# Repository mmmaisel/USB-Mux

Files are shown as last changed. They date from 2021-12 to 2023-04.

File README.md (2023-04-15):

# USB-Mux

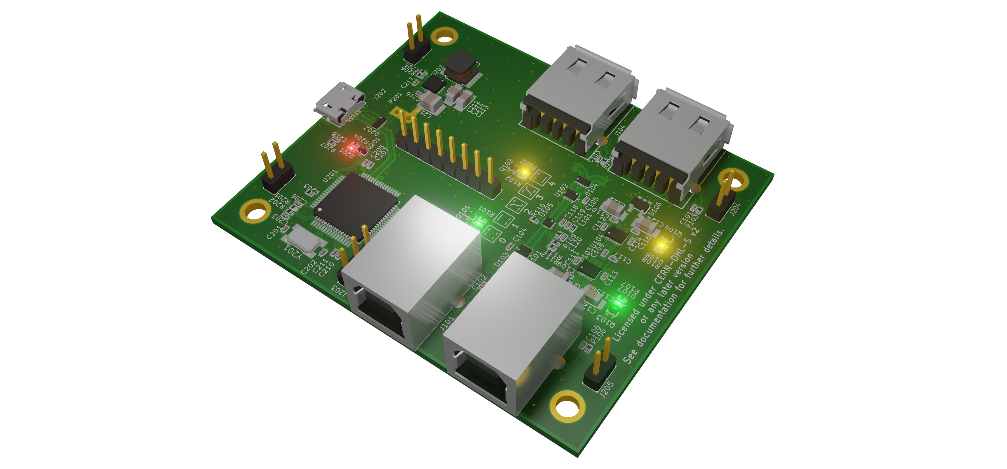
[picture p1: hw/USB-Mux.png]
USB-Mux Rendering


USB-Mux is an Open-Source and Open-Hardware 2x2 USB 2.0 multiplexer.

It supports a single connection between one of the inputs to one of the outputs.
Additionally, it can disconnect the outputs completely. Power flows from the
selected input to the selected output. Inactive output ports are powerless.

Possible applications are switching USB connections in automated tests
or power-cycle a hanging USB device via software.

Binary production files can be downloaded from the
[Releases](https://github.com/mmmaisel/USB-Mux/releases) page.

## Usage

The multiplexer is controlled over USB via a virtual terminal. The virtual
terminal will prompt "Mux:" and accepts a single number between 0 and 4 followed
by a newline to select the multiplexer position.
The meaning of the different numbers is printed on the PCB.

To connect to the virtual terminal on Linux you can use the following command:
`picocom /dev/ttyACM0`

## Programming

Configure the firmware build environment in the 'src' directory with meson
and the supplied cross compiler file.
`meson . build --cross-file cross.build`
Then go into the 'build' directory and build it with `ninja`.

Now, you can program the CPU on the USB-Mux PCB with OpenOCD and an ST-Nucleo
board as programmer with `ninja flash`.

## License

USB-Mux KiCAD hardware design files in the "hw" directory are licenses under the
CERN-OHL-S v2, or (at your option) any later version.

The USB-Mux firmware in the "src" directory is licensed under the
GNU GPLv3, or (at your option) any later version.

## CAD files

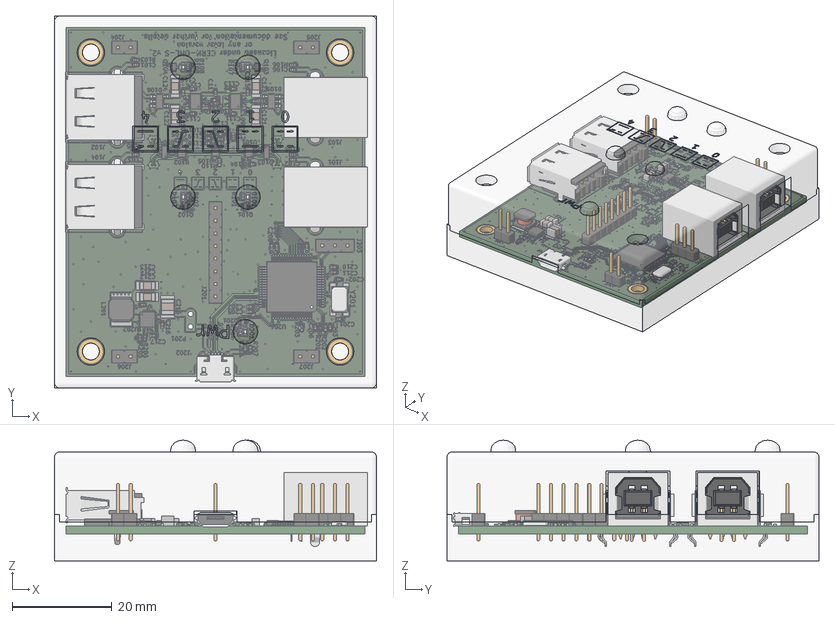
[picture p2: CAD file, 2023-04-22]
hw/USB-Mux-Case.FCStd
64.6 x 74.6 x 24.2 mm
Case-Bot
Case-Top

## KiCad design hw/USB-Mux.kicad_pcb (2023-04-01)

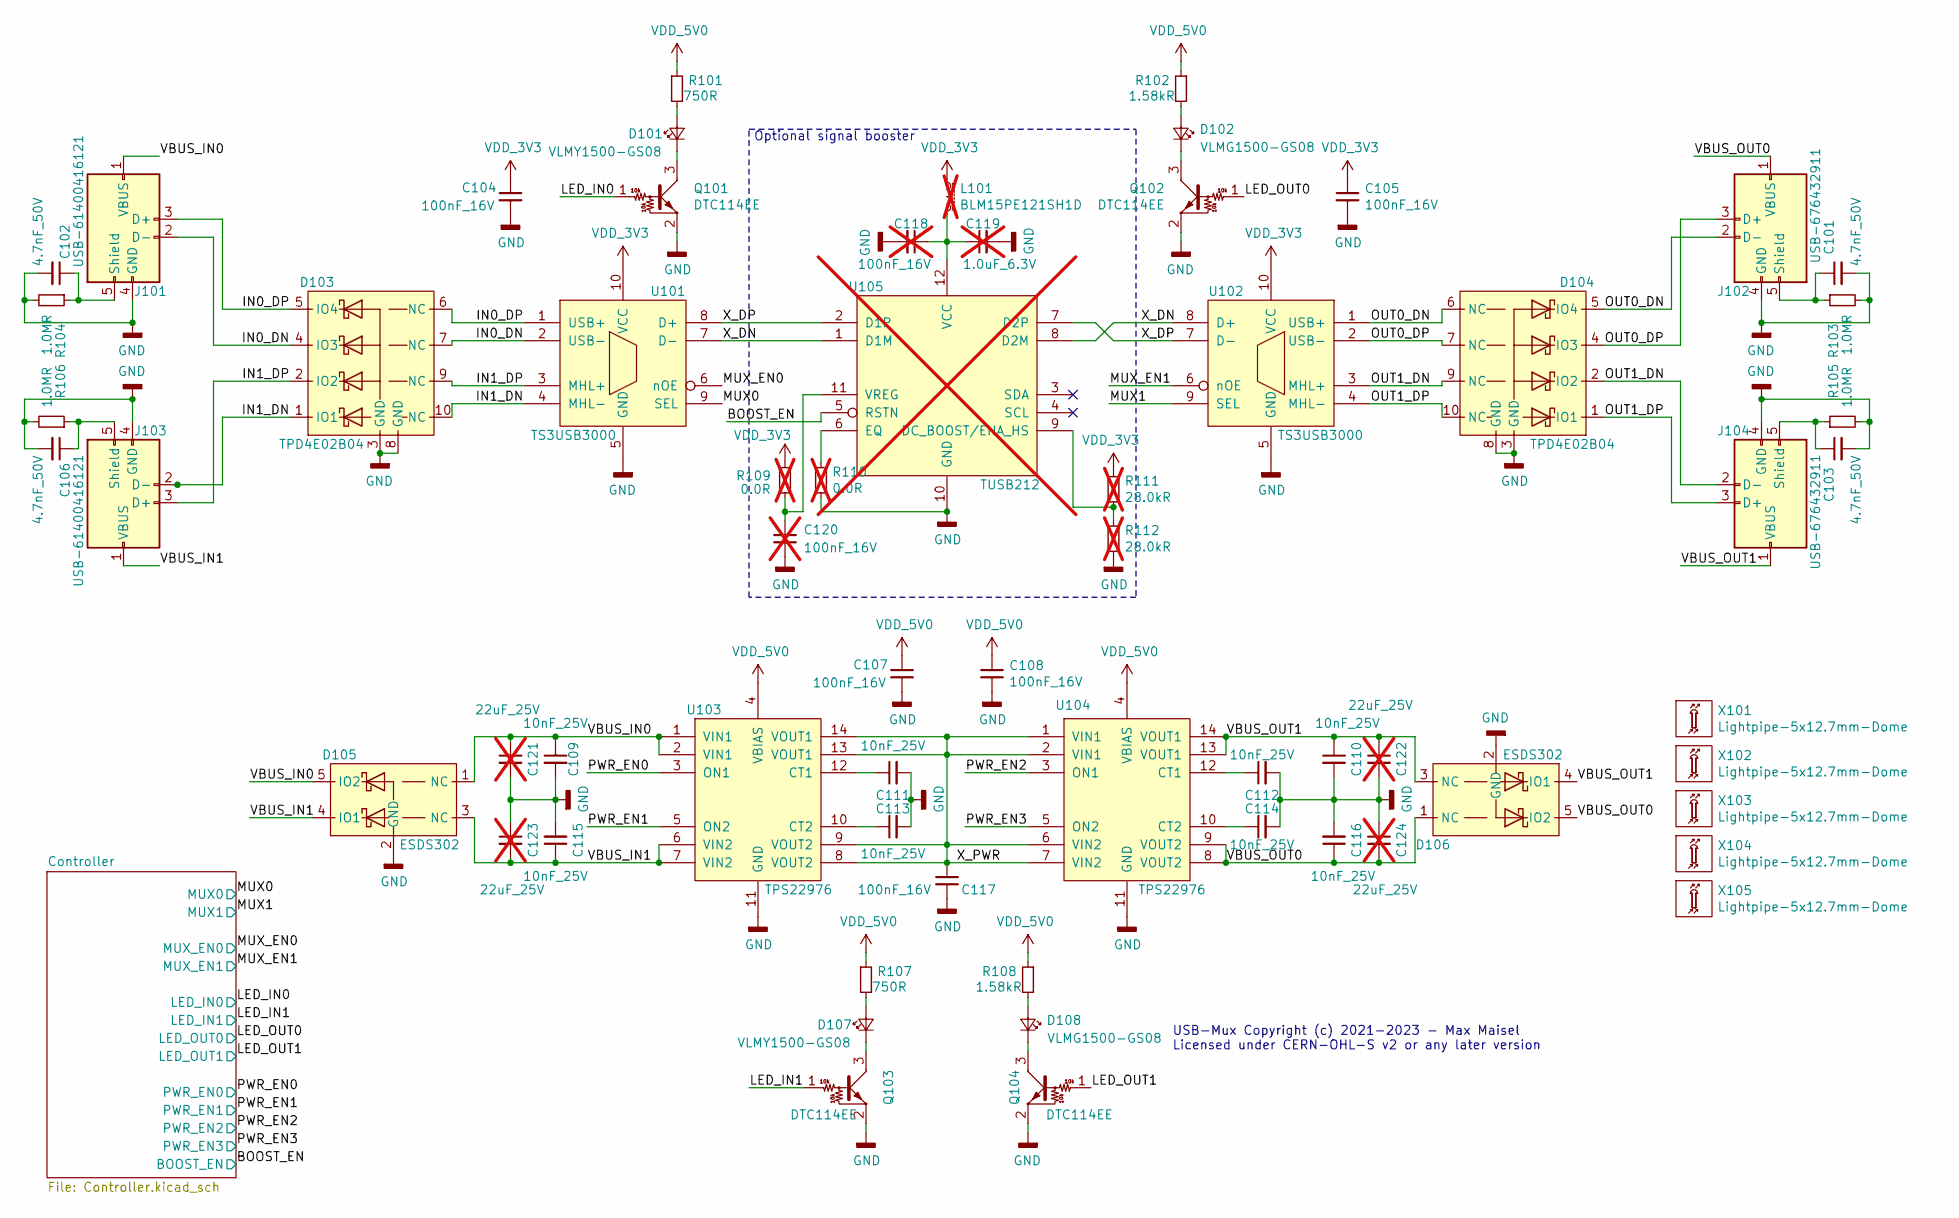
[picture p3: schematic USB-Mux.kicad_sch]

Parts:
C101, C102, C103, C106: 4.7nF_50V; C_0402; mouser# 810-CGA2B2X7R1H472K
C104, C105, C107, C108, C117: 100nF_16V; C_0402; mouser# 80-C0402C104K4R
C109, C110, C111, C112, C113, C114, C115, C116: 10nF_25V; C_0402; mouser# 603-CC0402KRX5R8BB10
C118, C120: 100nF_16V; C_0402; mouser# 80-C0402C104K4R; not fitted
C119: 1.0uF_6.3V; C_0402; mouser# 81-GRM152R60J105ME5D; not fitted
C121, C122, C123, C124: 22uF_25V; C_1206; mouser# 81-GRT31CR61E226ME1L; not fitted
D101, D107: VLMY1500-GS08; LED_0402; mouser# 78-VLMY1500-GS08
D102, D108: VLMG1500-GS08; LED_0402; mouser# 78-VLMG1500-GS08
D103, D104: TPD4E02B04; USON10; mouser# 595-TPD4E02B04DQAR
D105, D106: ESDS302; SOT-23-5; mouser# 595-ESDS302DBVR
J101, J103: USB-61400416121
J102, J104: USB-676432911; mouser# 649-87520-0012BLF
L101: BLM15PE121SH1D; L_0402; mouser# 81-BLM15PE121SH1D; not fitted
Q101, Q102, Q103, Q104: DTC114EE; SC-75; mouser# 863-DTC114EET1G
R101, R107: 750R; R_0402; mouser# 667-ERJ-XGNF7500Y
R102, R108: 1.58kR; R_0402; mouser# 667-ERJ-2RKF1581X
R103, R104, R105, R106: 1.0MR; R_0402; mouser# 667-ERJ-2RKF1004X
R109, R110: 0.0R; R_0402; mouser# 667-ERJ-2GE0R00X; not fitted
R111, R112: 28.0kR; R_0402; mouser# 667-ERJ-2RKF2802X; not fitted
U101, U102: TS3USB3000; UQFN10-RSE; mouser# 595-TS3USB3000RSER
U103, U104: TPS22976; WSON-14
U105: TUSB212; X2QFN12-RWB; mouser# 595-TUSB212RWBR; not fitted
X101, X102, X103, X104, X105: Lightpipe-5x12.7mm-Dome; Lightpipe-51513530500F; mouser# 645-51513530500F

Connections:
/BOOST_EN: U105.5 (RSTN); also elsewhere on the board
/IN0_DN: D103.4 (IO3), D103.7 (NC), J101.2 (D-), U101.2 (USB-)
/IN0_DP: D103.5 (IO4), D103.6 (NC), J101.3 (D+), U101.1 (USB+)
/IN1_DN: D103.1 (IO1), D103.10 (NC), J103.2 (D-), U101.4 (MHL-)
/IN1_DP: D103.2 (IO2), D103.9 (NC), J103.3 (D+), U101.3 (MHL+)
/LED_IN0: Q101.1 (B); also elsewhere on the board
/LED_IN1: Q103.1 (B); also elsewhere on the board
/LED_OUT0: Q102.1 (B); also elsewhere on the board
/LED_OUT1: Q104.1 (B); also elsewhere on the board
/MUX0: U101.9 (SEL); also elsewhere on the board
/MUX1: U102.9 (SEL); also elsewhere on the board
/MUX_EN0: U101.6 (nOE); also elsewhere on the board
/MUX_EN1: U102.6 (nOE); also elsewhere on the board
/OUT0_DN: D104.5 (IO4), D104.6 (NC), J102.2 (D-), U102.1 (USB+)
/OUT0_DP: D104.4 (IO3), D104.7 (NC), J102.3 (D+), U102.2 (USB-)
/OUT1_DN: D104.2 (IO2), D104.9 (NC), J104.2 (D-), U102.3 (MHL+)
/OUT1_DP: D104.1 (IO1), D104.10 (NC), J104.3 (D+), U102.4 (MHL-)
/PWR_EN0: U103.3 (ON1); also elsewhere on the board
/PWR_EN1: U103.5 (ON2); also elsewhere on the board
/PWR_EN2: U104.3 (ON1); also elsewhere on the board
/PWR_EN3: U104.5 (ON2); also elsewhere on the board
/VBUS_IN0: C109.1, C121.1, D105.1 (NC), D105.5 (IO2), J101.1 (VBUS), U103.1 (VIN1), U103.2 (VIN1)
/VBUS_IN1: C115.1, C123.2, D105.3 (NC), D105.4 (IO1), J103.1 (VBUS), U103.6 (VIN2), U103.7 (VIN2)
/VBUS_OUT0: C116.1, C124.2, D106.1 (NC), D106.5 (IO2), J102.1 (VBUS), U104.8 (VOUT2), U104.9 (VOUT2)
/VBUS_OUT1: C110.1, C122.1, D106.3 (NC), D106.4 (IO1), J104.1 (VBUS), U104.13 (VOUT1), U104.14 (VOUT1)
/X_DN: U101.7 (D-), U102.8 (D+), U105.1 (D1M), U105.8 (D2M)
/X_DP: U101.8 (D+), U102.7 (D-), U105.2 (D1P), U105.7 (D2P)
/X_PWR: C117.1, U103.8 (VOUT2), U103.9 (VOUT2), U103.13 (VOUT1), U103.14 (VOUT1), U104.1 (VIN1), U104.2 (VIN1), U104.6 (VIN2), U104.7 (VIN2)
GND: C101.2, C102.2, C103.2, C104.2, C105.2, C106.2, C107.2, C108.2, C109.2, C110.2, C111.2, C112.2, C113.2, C114.2, C115.2, C116.2, C117.2, C118.2, C119.2, C120.2, C121.2, C122.2, C123.1, C124.1, D103.3 (GND), D103.8 (GND), D104.3 (GND), D104.8 (GND), D105.2 (GND), D106.2 (GND), J101.4 (GND), J102.4 (GND), J103.4 (GND), J104.4 (GND), Q101.2 (E), Q102.2 (E), Q103.2 (E), Q104.2 (E), R103.2, R104.2, R105.2, R106.2, R110.2, R112.2, U101.5 (GND), U102.5 (GND), U103.11 (GND), U104.11 (GND), U105.10 (GND); also elsewhere on the board
unnamed: C101.1, J102.5 (Shield), R103.1
unnamed: C102.1, J101.5 (Shield), R104.1
unnamed: C103.1, J104.5 (Shield), R105.1
unnamed: C106.1, J103.5 (Shield), R106.1
unnamed: C111.1, U103.12 (CT1)
unnamed: C112.1, U104.12 (CT1)
unnamed: C113.1, U103.10 (CT2)
unnamed: C114.1, U104.10 (CT2)
unnamed: C118.1, C119.1, L101.2, U105.12 (VCC)
unnamed: C120.1, R109.1, U105.11 (VREG)
unnamed: D101.1 (K), Q101.3 (C)
unnamed: D101.2 (A), R101.2
unnamed: D102.1 (K), Q102.3 (C)
unnamed: D102.2 (A), R102.2
unnamed: D107.1 (K), Q103.3 (C)
unnamed: D107.2 (A), R107.2
unnamed: D108.1 (K), Q104.3 (C)
unnamed: D108.2 (A), R108.2
unnamed: R110.1, U105.6 (EQ)
unnamed: R111.2, R112.1, U105.9 (DC_BOOST/ENA_HS)
VDD_3V3: C104.1, C105.1, L101.1, R109.2, R111.1, U101.10 (VCC), U102.10 (VCC); also elsewhere on the board
VDD_5V0: C107.1, C108.1, R101.1, R102.1, R107.1, R108.1, U103.4 (VBIAS), U104.4 (VBIAS); also elsewhere on the board

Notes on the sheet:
Optional signal booster
USB-Mux Copyright (c) 2021-2023 - Max Maisel Licensed under CERN-OHL-S v2 or any later version

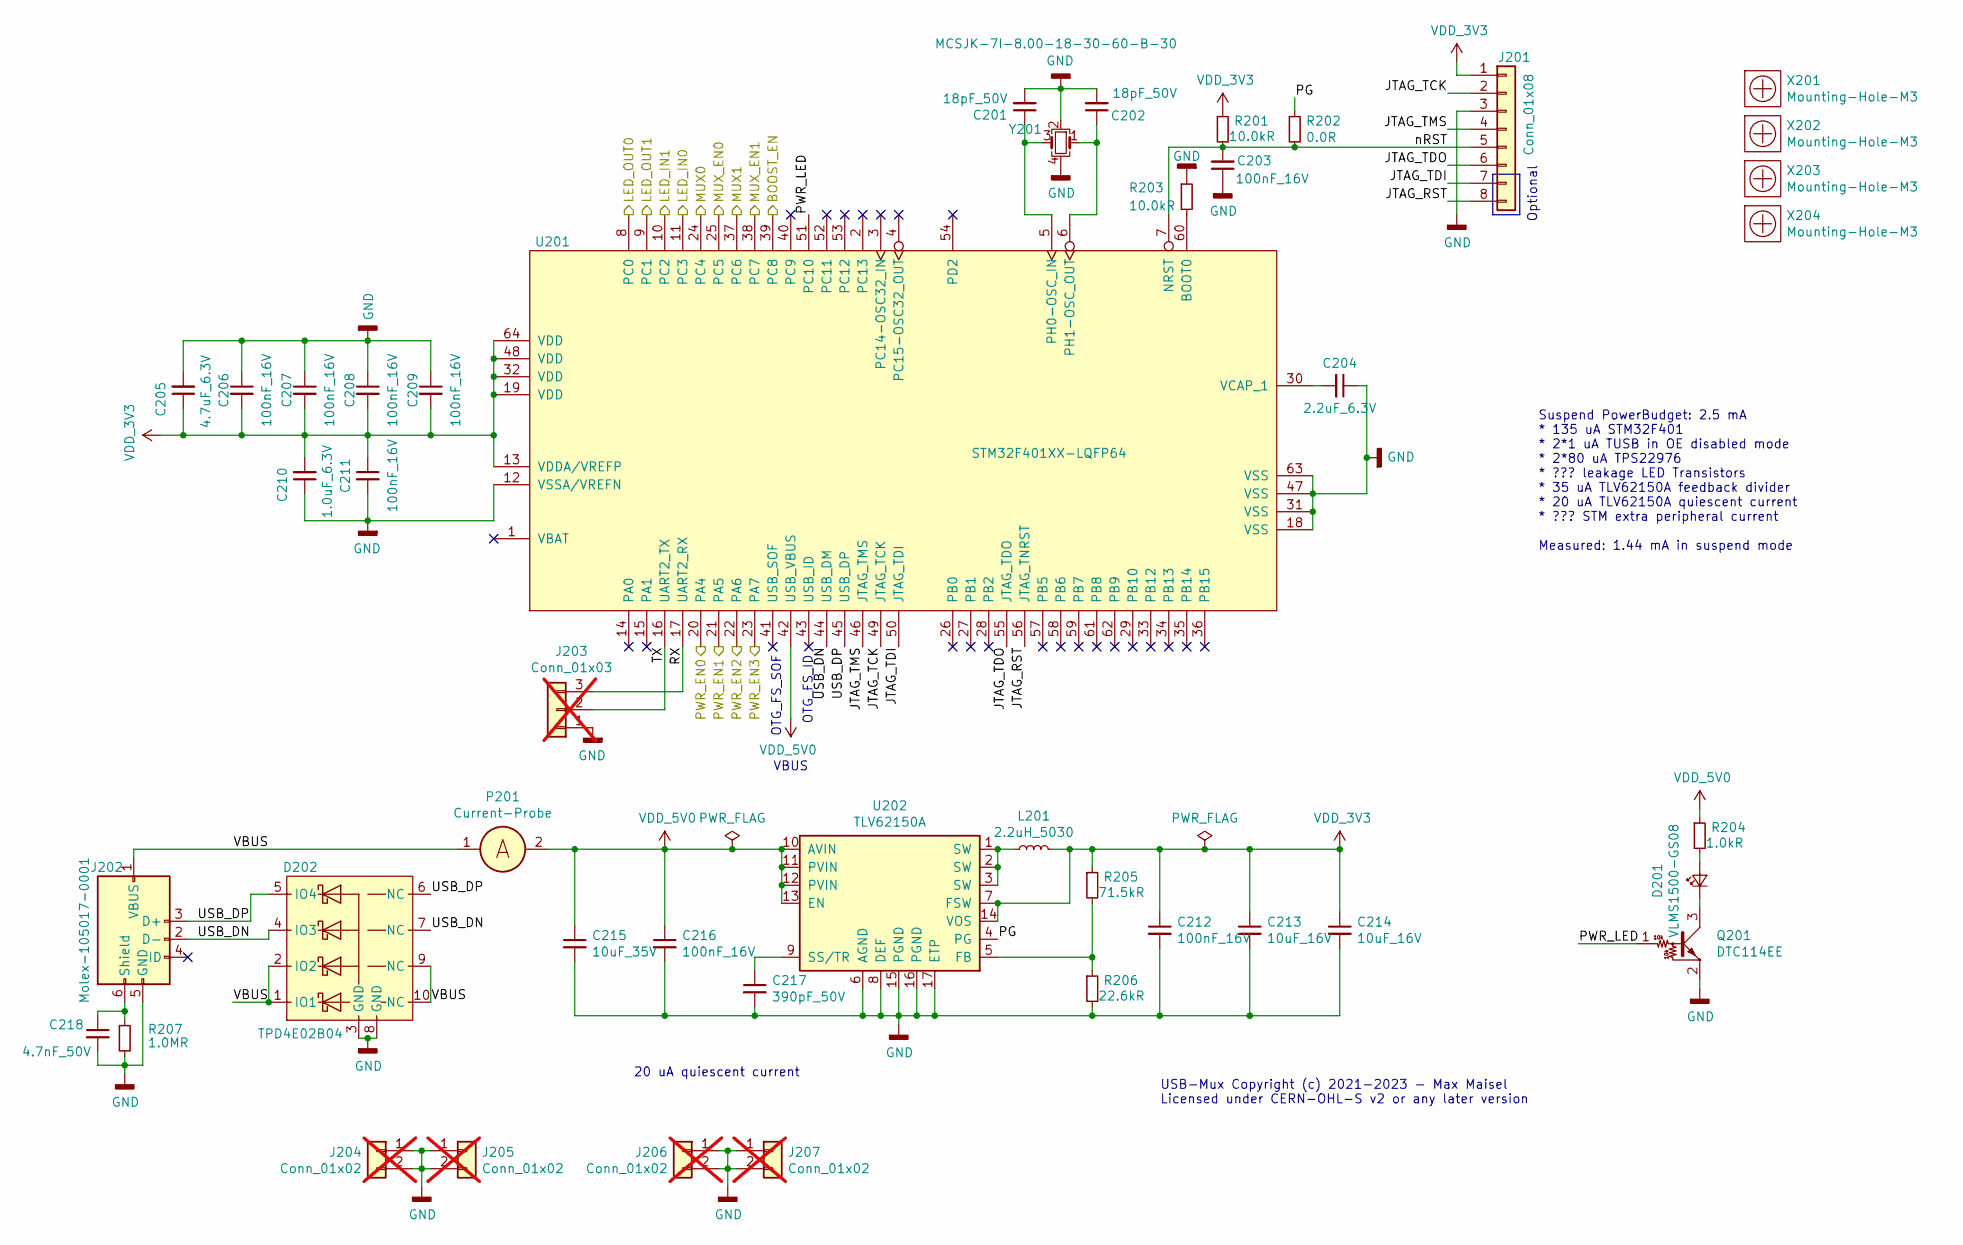
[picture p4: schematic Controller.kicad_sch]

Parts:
C201, C202: 18pF_50V; C_0402; mouser# 81-GRM1555C1H180FA1D
C203, C206, C207, C208, C209, C211, C212, C216: 100nF_16V; C_0402; mouser# 80-C0402C104K4R
C204: 2.2uF_6.3V; C_0402; mouser# 81-GRM155R60J225ME9D
C205: 4.7uF_6.3V; C_0402; mouser# 81-GRM155R60J475ME7D
C210: 1.0uF_6.3V; C_0402; mouser# 81-GRM152R60J105ME5D
C213, C214: 10uF_16V; C_1206; mouser# 80-C1206C106K4P
C215: 10uF_35V; C_1210; mouser# 963-GMK325BJ106KN-T
C217: 390pF_50V; C_0402; mouser# 81-GRM155R71H391KA1D
C218: 4.7nF_50V; C_0402; mouser# 810-CGA2B2X7R1H472K
D201: VLMS1500-GS08; LED_0402; mouser# 78-VLMS1500-GS08
D202: TPD4E02B04; USON10; mouser# 595-TPD4E02B04DQAR
J201: Conn_01x08; Pin_Header_Straight_1x08_Pitch2.54mm; farnell# 1593416
J202: Molex-105017-0001; microUSB-B-Molex-1050170-001; mouser# 538-105017-0001
J203: Conn_01x03; Pin_Header_Straight_1x03_Pitch2.54mm; farnell# 1593412; not fitted
J204, J205, J206, J207: Conn_01x02; Pin_Header_Straight_1x02_Pitch2.54mm; farnell# 1593411; not fitted
L201: 2.2uH_5030; L_Taiyo-Yuden_NR-50xx; mouser# 963-NRS5030T2R2NMGJV
P201: Current-Probe; Current-Probe-2.54
Q201: DTC114EE; SC-75; mouser# 863-DTC114EET1G
R201, R203: 10.0kR; R_0402; mouser# 667-ERJ-2RKF1002X
R202: 0.0R; R_0402; mouser# 667-ERJ-2GE0R00X
R204: 1.0kR; R_0402; mouser# 667-ERJ-2RKF1001X
R205: 71.5kR; R_0402; mouser# 667-ERJ-2RKF7152X
R206: 22.6kR; R_0402; mouser# 667-ERJ-S02F2262X
R207: 1.0MR; R_0402; mouser# 667-ERJ-2RKF1004X
U201: STM32F401XX-LQFP64; LQFP-64
U202: TLV62150A; VQFN16-RGT; mouser# 595-TLV62150ARGTR
X201, X202, X203, X204: Mounting-Hole-M3
Y201: MCSJK-7I-8.00-18-30-60-B-30; Crystal_SMD_Multicomp_5032; farnell# 2854013

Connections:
/BOOST_EN: U201.39 (PC8); also elsewhere on the board
/Controller/JTAG_RST: J201.8, U201.56 (JTAG_TNRST)
/Controller/JTAG_TCK: J201.2, U201.49 (JTAG_TCK)
/Controller/JTAG_TDI: J201.7, U201.50 (JTAG_TDI)
/Controller/JTAG_TDO: J201.6, U201.55 (JTAG_TDO)
/Controller/JTAG_TMS: J201.4, U201.46 (JTAG_TMS)
/Controller/PG: R202.1, U202.4 (PG)
/Controller/PWR_LED: Q201.1 (B), U201.51 (PC10)
/Controller/RX: J203.3, U201.17 (UART2_RX)
/Controller/TX: J203.2, U201.16 (UART2_TX)
/Controller/USB_DN: D202.4 (IO3), D202.7 (NC), J202.2 (D-), U201.44 (USB_DM)
/Controller/USB_DP: D202.5 (IO4), D202.6 (NC), J202.3 (D+), U201.45 (USB_DP)
/Controller/VBUS: D202.1 (IO1), D202.2 (IO2), D202.9 (NC), D202.10 (NC), J202.1 (VBUS), P201.1
/Controller/nRST: C203.2, J201.5, R201.2, R202.2, U201.7 (NRST)
/LED_IN0: U201.11 (PC3); also elsewhere on the board
/LED_IN1: U201.10 (PC2); also elsewhere on the board
/LED_OUT0: U201.8 (PC0); also elsewhere on the board
/LED_OUT1: U201.9 (PC1); also elsewhere on the board
/MUX0: U201.24 (PC4); also elsewhere on the board
/MUX1: U201.37 (PC6); also elsewhere on the board
/MUX_EN0: U201.25 (PC5); also elsewhere on the board
/MUX_EN1: U201.38 (PC7); also elsewhere on the board
/PWR_EN0: U201.20 (PA4); also elsewhere on the board
/PWR_EN1: U201.21 (PA5); also elsewhere on the board
/PWR_EN2: U201.22 (PA6); also elsewhere on the board
/PWR_EN3: U201.23 (PA7); also elsewhere on the board
GND: C201.2, C202.2, C203.1, C204.1, C205.2, C206.1, C207.1, C208.1, C209.1, C210.1, C211.2, C212.2, C213.2, C214.2, C215.2, C216.2, C217.2, C218.2, D202.3 (GND), D202.8 (GND), J201.3, J202.5 (GND), J203.1, J204.1, J204.2, J205.1, J205.2, J206.1, J206.2, J207.1, J207.2, Q201.2 (E), R203.1, R206.2, R207.2, U201.12 (VSSA/VREFN), U201.18 (VSS), U201.31 (VSS), U201.47 (VSS), U201.63 (VSS), U202.6 (AGND), U202.8 (DEF), U202.15 (PGND), U202.16 (PGND), U202.17 (ETP), Y201.2, Y201.4; also elsewhere on the board
unnamed: C201.1, U201.5 (PH0-OSC_IN), Y201.3
unnamed: C202.1, U201.6 (PH1-OSC_OUT), Y201.1
unnamed: C204.2, U201.30 (VCAP_1)
unnamed: C217.1, U202.9 (SS/TR)
unnamed: C218.1, J202.6 (Shield), R207.1
unnamed: D201.1 (K), Q201.3 (C)
unnamed: D201.2 (A), R204.2
unnamed: L201.1, U202.1 (SW), U202.2 (SW), U202.3 (SW)
unnamed: R203.2, U201.60 (BOOT0)
unnamed: R205.2, R206.1, U202.5 (FB)
VDD_3V3: C205.1, C206.2, C207.2, C208.2, C209.2, C210.2, C211.1, C212.1, C213.1, C214.1, J201.1, L201.2, R201.1, R205.1, U201.13 (VDDA/VREFP), U201.19 (VDD), U201.32 (VDD), U201.48 (VDD), U201.64 (VDD), U202.7 (FSW), U202.14 (VOS); also elsewhere on the board
VDD_5V0: C215.1, C216.1, P201.2, R204.1, U201.42 (USB_VBUS), U202.10 (AVIN), U202.11 (PVIN), U202.12 (PVIN), U202.13 (EN); also elsewhere on the board

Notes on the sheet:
USB-Mux Copyright (c) 2021-2023 - Max Maisel Licensed under CERN-OHL-S v2 or any later version
VBUS
OTG_FS_SOF
Optional
20 uA quiescent current
OTG_FS_ID
Suspend PowerBudget: 2.5 mA * 135 uA STM32F401 * 2*1 uA TUSB in OE disabled mode * 2*80 uA TPS22976 * ??? leakage LED Transistors * 35 uA TLV62150A feedback divider * 20 uA TLV62150A quiescent current * ??? STM extra peripheral current Measured: 1.44 mA in suspend mode

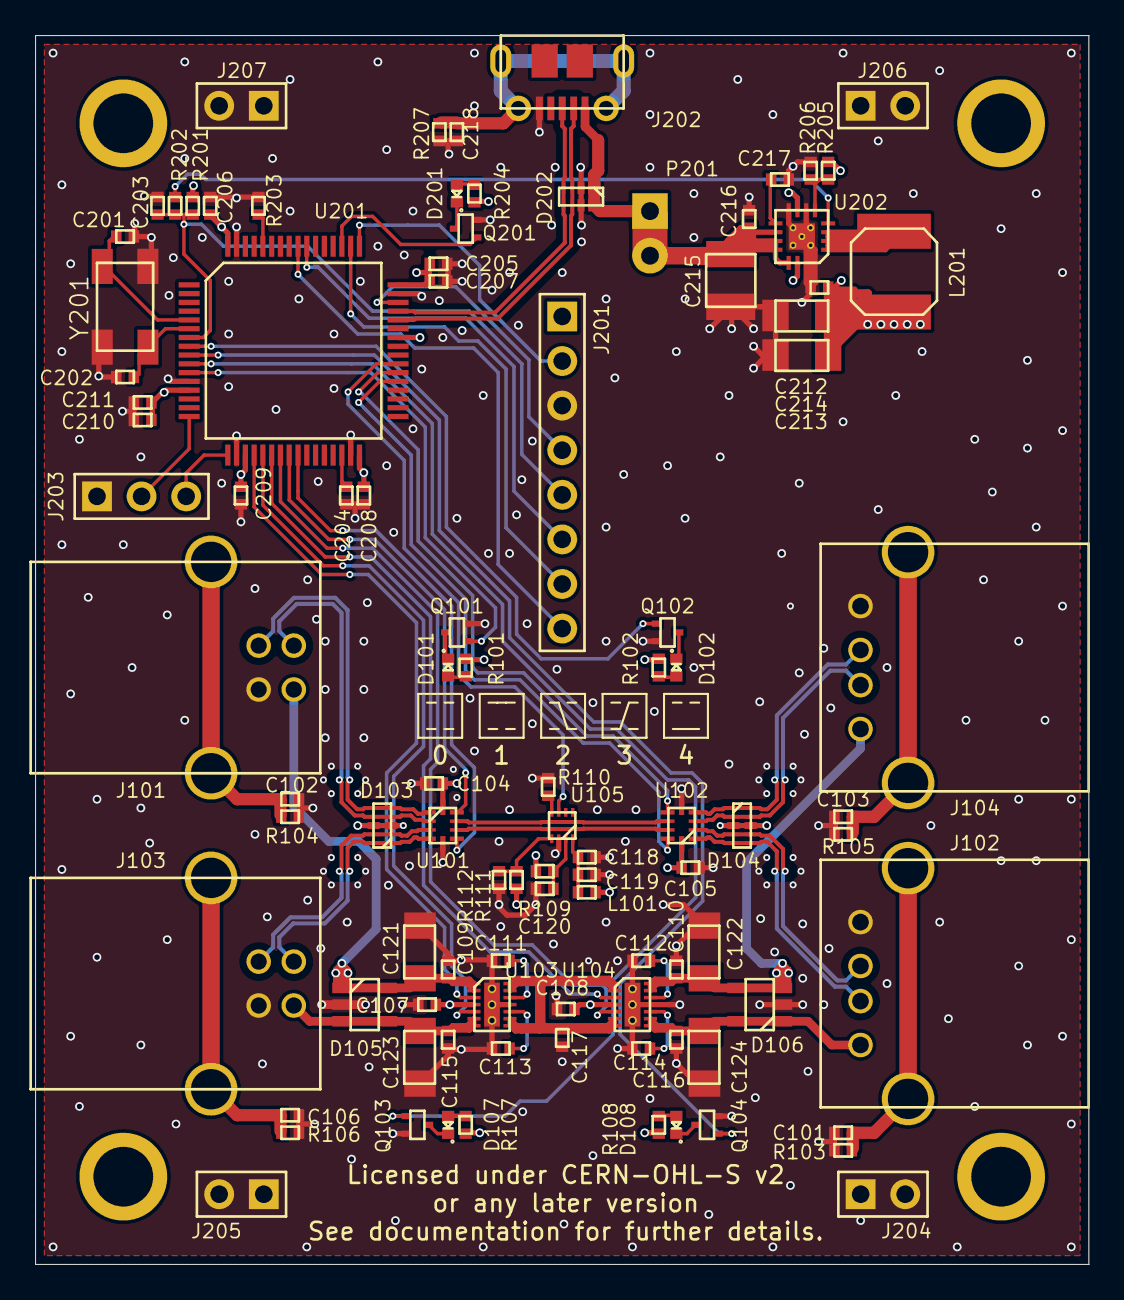
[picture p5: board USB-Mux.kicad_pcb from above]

Board: 6 copper layers, 60.0 x 70.0 mm, 107 parts (0 on the bottom side), 74 nets.

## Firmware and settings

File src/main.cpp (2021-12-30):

/**********************************************************************\
 * USB-Mux
 *
 * C++ main function
 *  - please note that the real program starts in startup.cpp
 **********************************************************************
 * Copyright (C) 2019-2021 - Max Maisel
 *
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
 * You should have received a copy of the GNU General Public License
 * along with this program.  If not, see <http://www.gnu.org/licenses/>.
\**********************************************************************/
/// @file
#include <string.h>
#include <stdlib.h>

#include "system.h"
#include "usb_mux.h"

#include "usb_phy.h"

/// C++ main function, program starts here.
void main() __attribute__((noreturn));
void main() {
    USBPhy::Initialize();
    UsbMux::initialize();
    for(;;);
}

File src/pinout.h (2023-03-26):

/**********************************************************************\
 * USB-Mux
 *
 * Pinout difinitions
 **********************************************************************
 * Copyright (C) 2021 - Max Maisel
 *
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
 * You should have received a copy of the GNU General Public License
 * along with this program.  If not, see <http://www.gnu.org/licenses/>.
\**********************************************************************/
#pragma once

#include "types.h"
#include "dev/gpio.h"

namespace pinout {
    enum : WORD {
        // PORTA
        PWREN0 = (1 << 4),
        PWREN1 = (1 << 5),
        PWREN2 = (1 << 6),
        PWREN3 = (1 << 7),

        // PORTC
        LED_OUT0 = (1 << 0),
        LED_OUT1 = (1 << 1),
        LED_IN1 = (1 << 2),
        LED_IN0 = (1 << 3),
        MUX0 = (1 << 4),
        MUXDIS0 = (1 << 5),
        MUX1 = (1 << 6),
        MUXDIS1 = (1 << 7),
        BOOSTDIS = (1 << 8),
        LED_PWR = (1 << 10)
    };

    enum : WORD {
        // PORTA
        MODE_PWREN0 = (dev::gpio::OUTPUT << (2*4)),
        MODE_PWREN1 = (dev::gpio::OUTPUT << (2*5)),
        MODE_PWREN2 = (dev::gpio::OUTPUT << (2*6)),
        MODE_PWREN3 = (dev::gpio::OUTPUT << (2*7)),

        MODE_VBUS = (dev::gpio::ALTERNATE << (2*9)),
        MODE_DM = (dev::gpio::ALTERNATE << (2*11)),
        MODE_DP = (dev::gpio::ALTERNATE << (2*12)),

        // PORTC
        MODE_LED_OUT0 = (dev::gpio::OUTPUT << (2*0)),
        MODE_LED_OUT1 = (dev::gpio::OUTPUT << (2*1)),
        MODE_LED_IN1 = (dev::gpio::OUTPUT << (2*2)),
        MODE_LED_IN0 = (dev::gpio::OUTPUT << (2*3)),
        MODE_MUX0 = (dev::gpio::OUTPUT << (2*4)),
        MODE_MUXDIS0 = (dev::gpio::OUTPUT << (2*5)),
        MODE_MUX1 = (dev::gpio::OUTPUT << (2*6)),
        MODE_MUXDIS1 = (dev::gpio::OUTPUT << (2*7)),
        MODE_BOOSTDIS = (dev::gpio::OUTPUT << (2*8)),
        MODE_LED_PWR = (dev::gpio::OUTPUT << (2*10))
    };

    enum : WORD {
        AFRH_VBUS = (10 << (4*(9-8))),
        AFRH_DM = (10 << (4*(11-8))),
        AFRH_DP = (10 << (4*(12-8)))
    };

    enum : WORD {
        PUPD_MUXDIS1 = (dev::gpio::PULLUP << (2*5)),
        PUPD_MUXDIS0 = (dev::gpio::PULLUP << (2*7)),
        PUPD_BOOSTDIS = (dev::gpio::PULLUP << (2*8))
    };
}

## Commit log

2021-12-30 Commit USB-Mux KiCAD library.
2021-12-30 Add USB-Mux hardware design.
    [Controller.sch, USB-Mux.kicad_pcb, USB-Mux.sch]
2021-12-30 Add minimal firmware.
    [st_nucleo_f401re.cfg]
2021-12-30 Fix swapped pin label in USB-Mux schematic.
    [Controller.sch, USB-Mux.sch]
2021-12-30 Implement USB physical device driver.
    Needs endpoint driver to compile.
2021-12-30 Implement USB endpoint device driver.
2021-12-30 Implement USB Descriptors, currently for a keyboard.
2021-12-30 Add SMA-73251-1150 component, footprint and 3D model.
2021-12-30 Add TPD4E02B04 component, footprint and 3D model.
2021-12-30 Add ESDS302 component, footprint and 3D model.
2021-12-30 Add TS3USB3000RSER component, footprint and 3D model.
2021-12-30 Add TUSB212 and TUSB216 component, footprint and 3D model.
2021-12-30 OpenOCD: Connect under reset.
    [st_nucleo_f401re.cfg]
2021-12-30 Add two more basic connector components, footprints and 3D models.
2021-12-30 Add 100R resistor component.
2022-01-10 Add BLM15PE121SH1D component, footprint and 3D model.
2022-01-12 Update USB-Mux schematic.
    Use new USB-Mux chip, add redriver and ESD protection.
    [Controller.sch, USB-Mux.sch]
2022-01-15 Layout USB-Mux rev2.
    [USB-Mux.kicad_pcb]
2022-01-27 Update project to KiCad 6 file formats.
    [Controller.kicad_sch, Controller.sch, USB-Mux.kicad_pcb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]
2022-02-24 Cleanup Library
    Remove unused ESD diode component and consistently name resistors X.XR.
    [Controller.kicad_sch, USB-Mux.kicad_sch]
2022-02-24 Use alternate functions for STM32 pins.
    [Controller.kicad_sch]
2023-01-30 Improve Layout, use impedances from manufacturer.
    [USB-Mux.kicad_pcb]
2023-03-29 Add case for the USB-Mux device.
    [USB-Mux-Case.FCStd]
2023-04-01 Upgrade project to KiCAD 7.0.
    [Controller.kicad_sch, USB-Mux.kicad_pcb, USB-Mux.kicad_sch]
2023-04-01 Mark dnp components in schematic.
    [Controller.kicad_sch, USB-Mux.kicad_pcb, USB-Mux.kicad_sch]
2023-04-22 Use VID/PID from pid.codes.
2023-04-22 Add some missing component ordering numbers.
    [Controller.kicad_sch, USB-Mux.kicad_sch]
2023-04-22 Increase Case-Top text and lightpipe hole size.
    [USB-Mux-Case.FCStd]

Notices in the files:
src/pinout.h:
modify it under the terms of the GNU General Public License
